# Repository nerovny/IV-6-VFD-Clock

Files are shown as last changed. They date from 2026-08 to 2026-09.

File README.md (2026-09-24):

# ИВ-6 VFD Digital Clock
+ _board: revision 1.0.0_
+ _firmware: version 0.1 Alpha_
## Overview
This is a basic 6-digit, 7-segment clock based on Soviet ИВ-6 vacuum fluorescent tubes, powered by a widely accessible STM32F103CBT6 microcontroller. 

+ No AI
+ No WiFi
+ USB-C powered

The core concept involves using a single 5V (USB-C) power source and converting the voltage to the 3.3V, 1.2V, and 30–35V levels required to operate the VFD tubes, microcontroller, and logic ICs. 
These circuits can be seen around the location of the rotary encoder on the right side of the board.

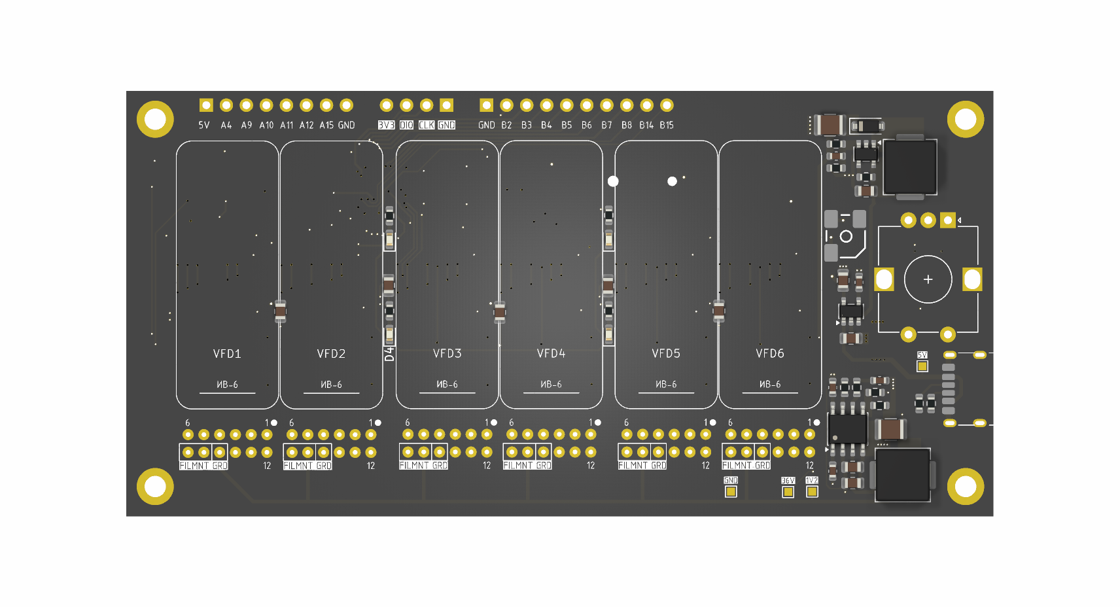
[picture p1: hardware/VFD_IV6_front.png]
main_view


The circuit employs sequential updating of CD4511 BCD-to-7-segment latches and static control of the vacuum fluorescent tubes using TBD62783A eight-channel drivers. 
The static function of the VFD eliminates the flickering, extends the life of the lamps, but requires much more ICs.

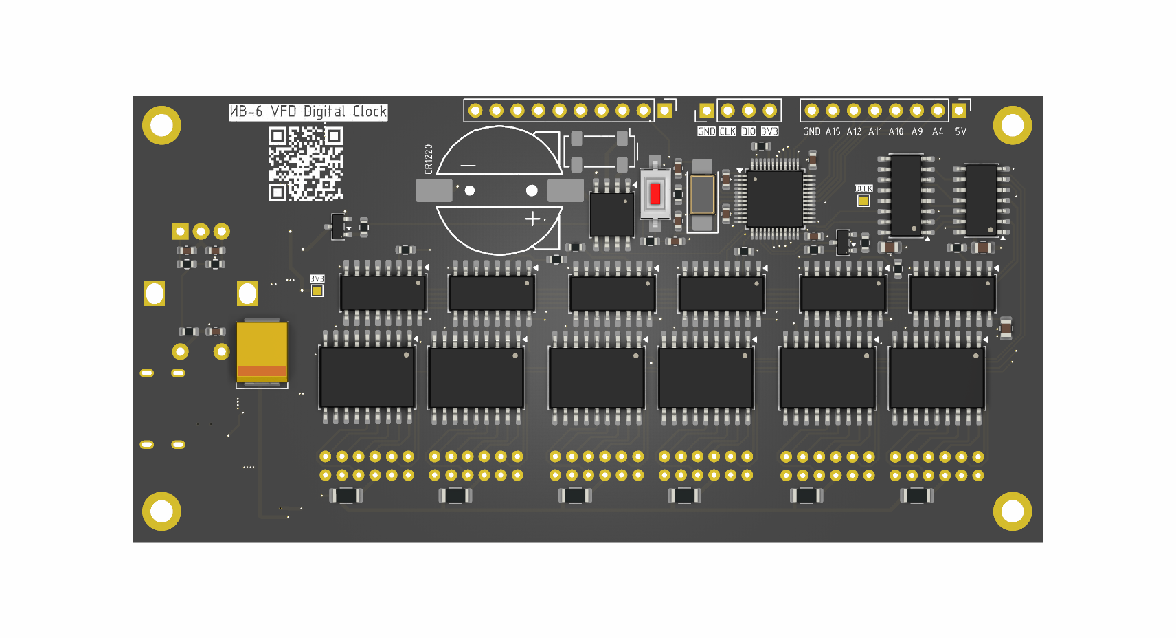
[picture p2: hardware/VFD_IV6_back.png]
rear_view


The unused MCU pins and 5v, 3v3 power rails are accessible via the 2.54mm headers and can be used for an additional LEDs, buttons, logic circuitry etc.

## Hardware
The 110x54mm 4-layer board is tight, but definitely doable by hand with the good iron. The road is mastered by the one who walks it.
+ [Interactive BOM HTML](http://htmlpreview.github.io/?https://github.com/nerovny/IV-6-VFD-Clock/blob/main/hardware/bom/ibom.html)
+ [Board dimensions](hardware/VFD_IV6_dimensions.png)
+ [Fabrication files]

## Firmware
The latest binary is [HERE](https://github.com/nerovny/IV-6-VFD-Clock/releases)

Use the onboard SWD header and STM32CubeProgrammer to flash it.

The firmware made with VSCode + PlatformIO using some HAL drivers. Source code is provided: just clone the repo and open the project with PIO VSCode plugin.

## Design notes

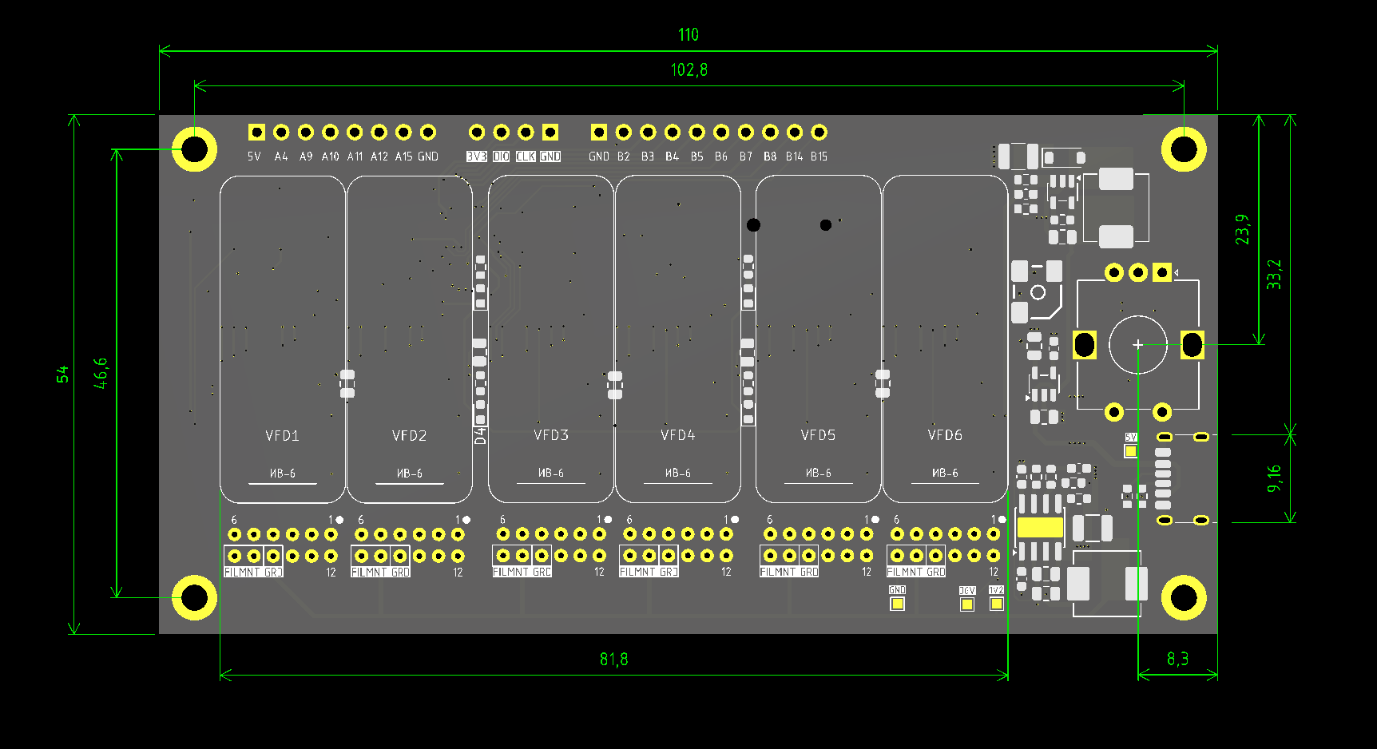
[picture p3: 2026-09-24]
hardware/VFD_IV6_dimensions.png

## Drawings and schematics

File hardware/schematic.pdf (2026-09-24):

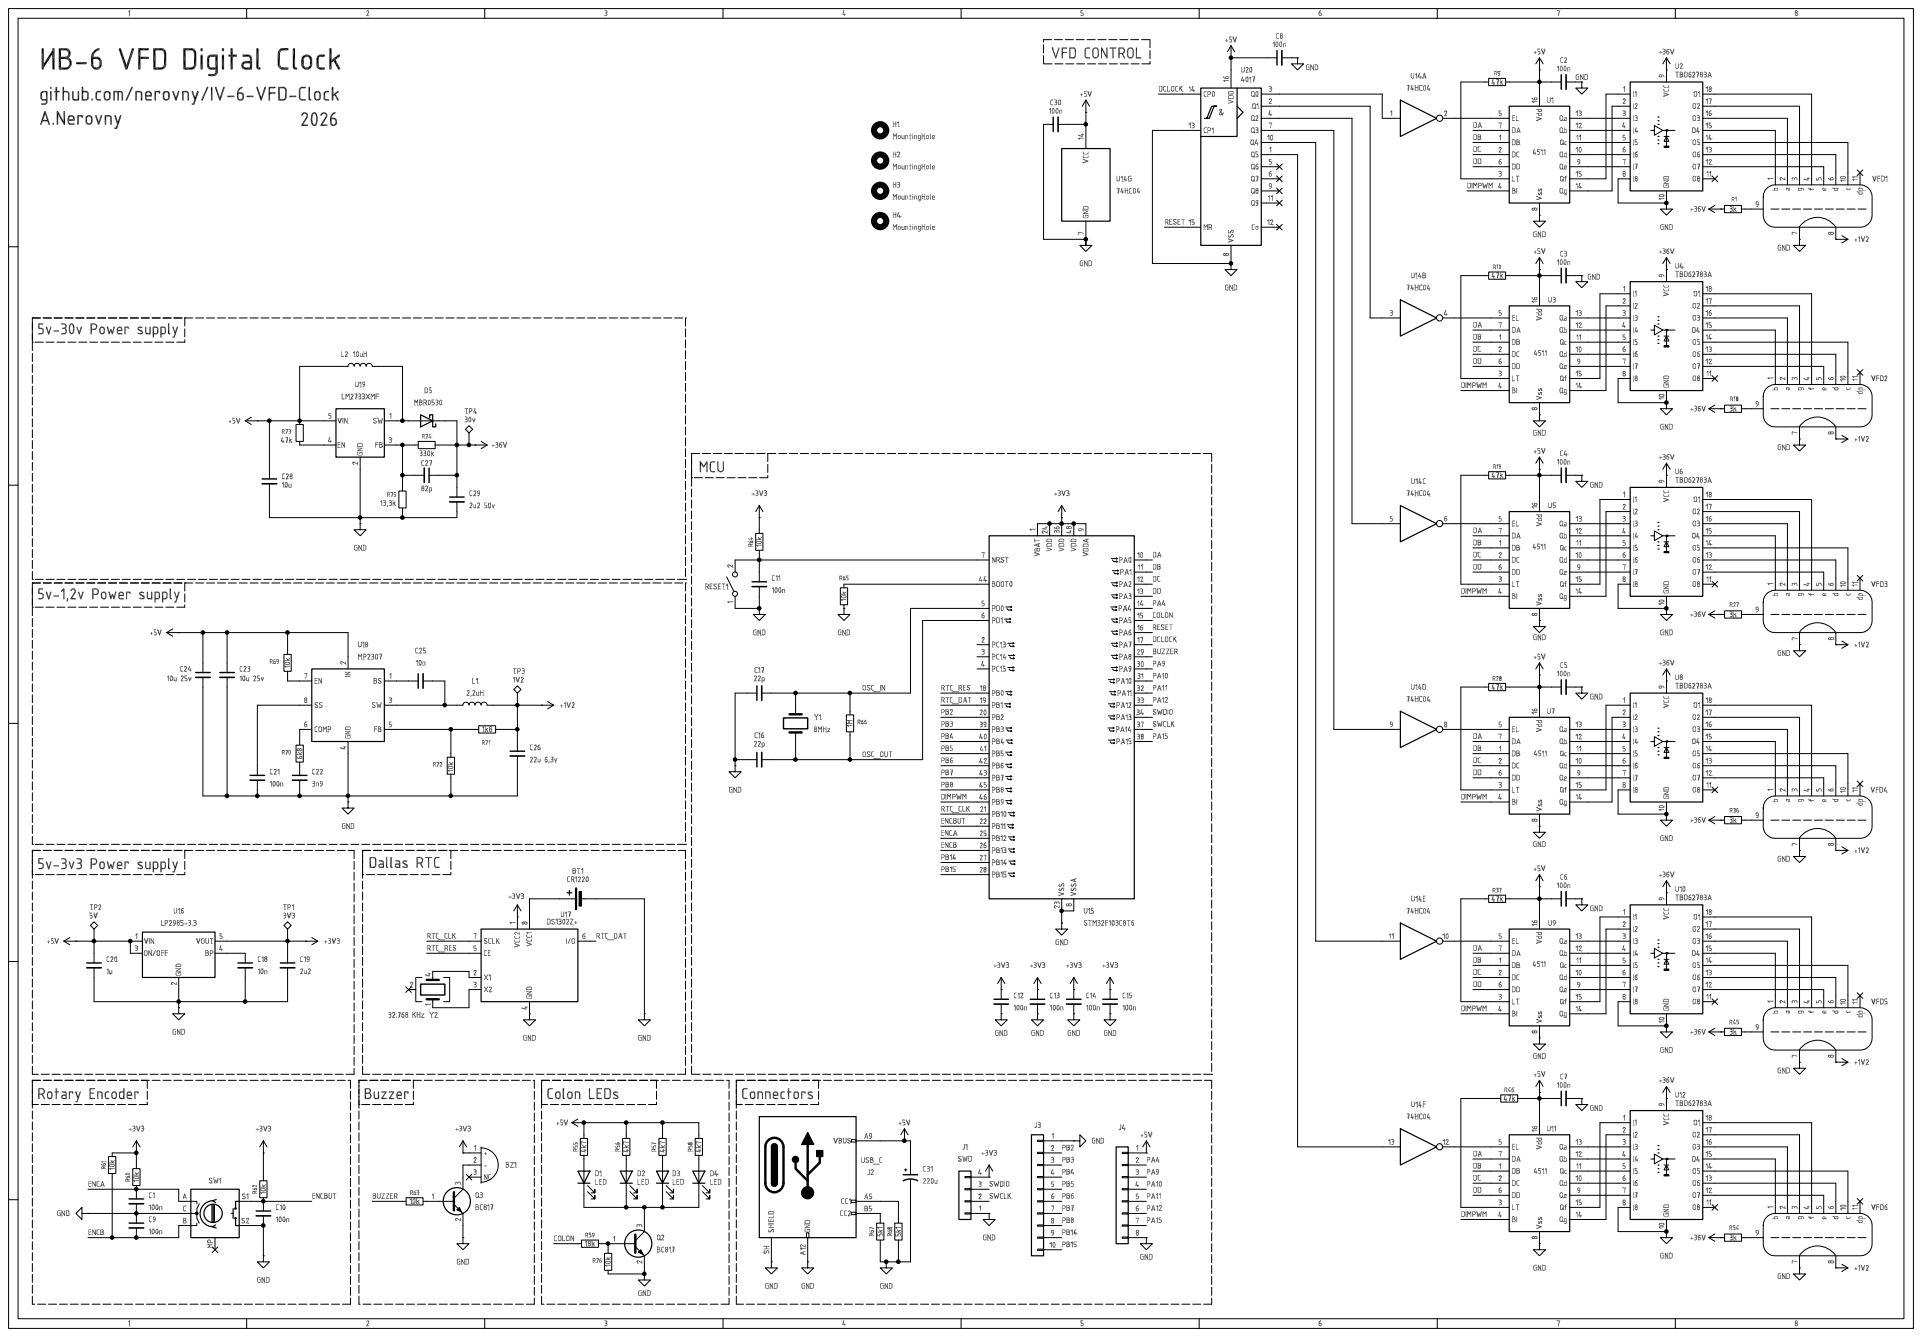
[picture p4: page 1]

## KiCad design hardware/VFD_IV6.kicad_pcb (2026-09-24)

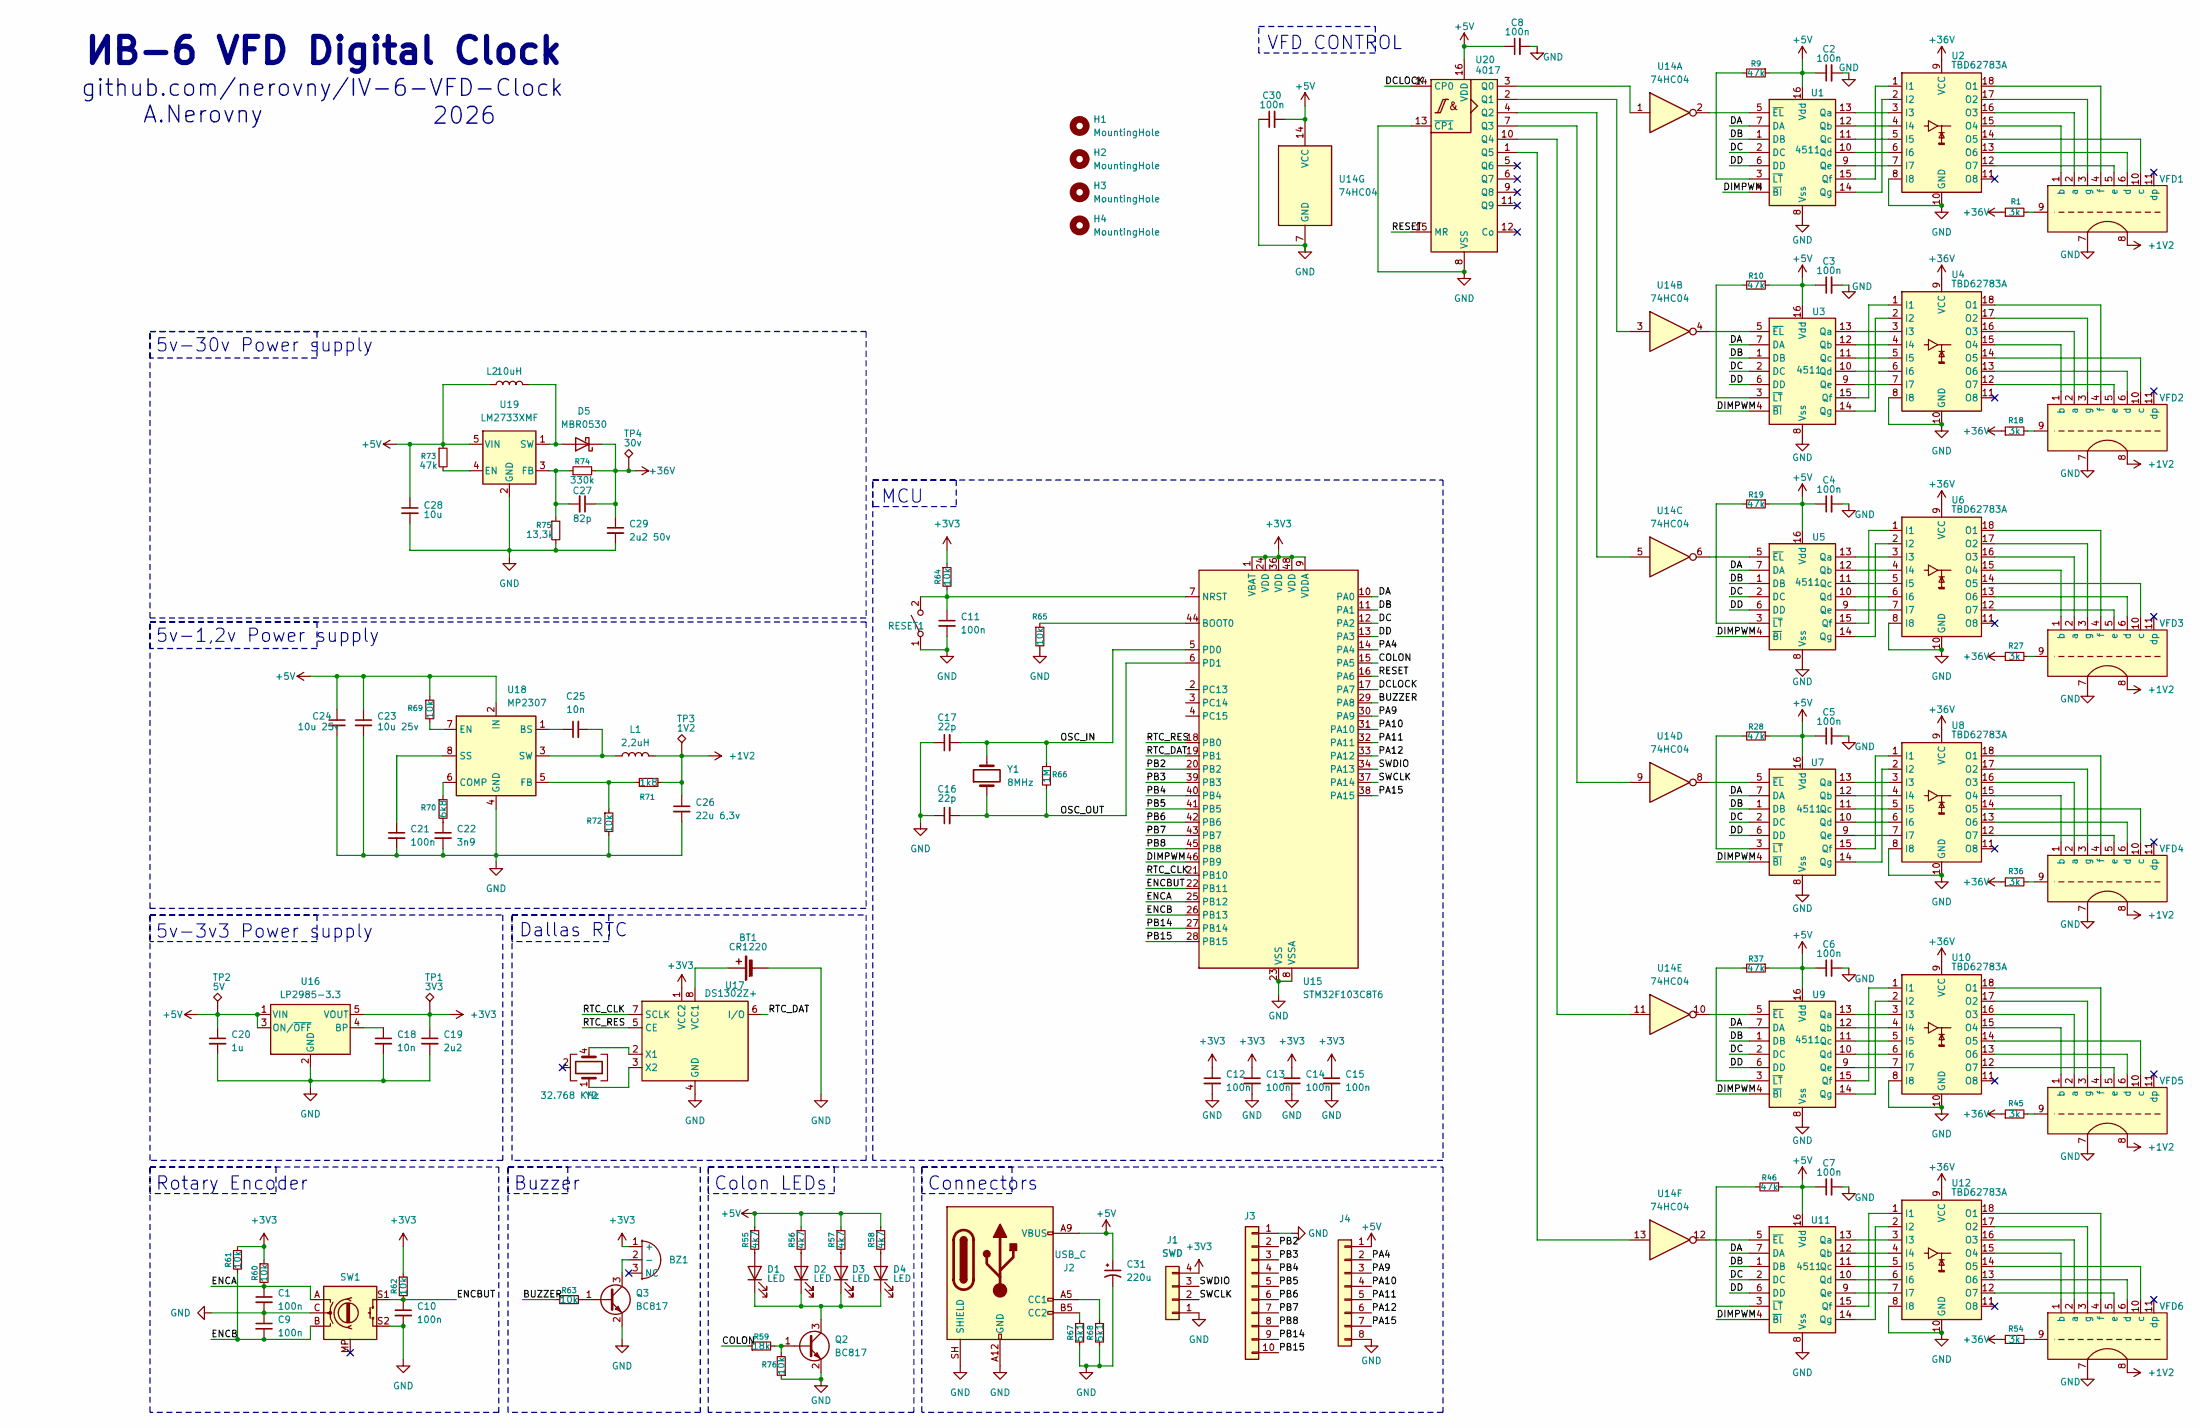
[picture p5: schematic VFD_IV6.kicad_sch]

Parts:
BT1: CR1220; RSPRO1220
BZ1: HCT5020
C1, C9, C10, C11, C12, C13, C14, C15, C21: 100n; C_0603_1608Metric
C2, C3, C4, C5, C6, C7, C8, C30: 100n; C_0805_2012Metric
C16, C17: 22p; C_0603_1608Metric
C18, C25: 10n; C_0603_1608Metric
C19: 2u2; C_0805_2012Metric
C20: 1u; C_0805_2012Metric
C22: 3n9; C_0603_1608Metric
C23, C24: 10u 25v; C_0805_2012Metric
C26: 22u 6,3v; C_1210_3225Metric
C27: 82p; C_0603_1608Metric
C28: 10u; C_0805_2012Metric
C29: 2u2 50v; C_1210_3225Metric
C31: 220u; CP_EIA-7360-38_Kemet-E
D1, D2, D3, D4: LED; LED_0603_1608Metric
D5: MBR0530; D_SOD-123
H1, H2, H3, H4: MountingHole; MountingHole_2.7mm_M2.5_DIN965_Pad
J1: SWD; PinHeader_1x04_P2.54mm_Vertical
J2: USB_C; USB_C_Receptacle_HRO_TYPE-C-31-M-17
J3: Conn_01x10; PinHeader_1x10_P2.54mm_Vertical
J4: Conn_01x06; PinHeader_1x08_P2.54mm_Vertical
L1: 2,2uH; L_APV_APH0650
L2: 10uH; L_APV_APH0650
Q2, Q3: BC817; SOT-23
R1, R18, R27, R36, R45, R54: 3k; R_1206_3216Metric
R9, R10, R19, R28, R37, R46, R73: 47k; R_0603_1608Metric
R55, R56, R57, R58: 4k7; R_0603_1608Metric
R59: 18k; R_0603_1608Metric
R60, R61, R62, R63, R64, R65, R69, R72, R76: 10k; R_0603_1608Metric
R66: 1M; R_0603_1608Metric
R67, R68: 5k1; R_0603_1608Metric
R70: 6k8; R_0603_1608Metric
R71: 1k8; R_0603_1608Metric
R74: 330k; R_0603_1608Metric
R75: 13,3k; R_0603_1608Metric
RESET1: SW_SPST; SW_SPST_CK_RS282G05A3
SW1: RotaryEncoder_Switch_MP; RotaryEncoder_Alps_EC12E-Switch_Vertical_H20mm
TP1: 3V3; TestPoint_Pad_1.0x1.0mm
TP2: 5V; TestPoint_Pad_1.0x1.0mm
TP3: 1V2; TestPoint_Pad_1.0x1.0mm
TP4: 30v; TestPoint_Pad_1.0x1.0mm
U1, U3, U5, U7, U9, U11: 4511; SOP-16_4.4x10.4mm_P1.27mm
U2, U4, U6, U8, U10, U12: TBD62783A; SOIC-18W_7.5x11.6mm_P1.27mm
U14: 74HC04; SOIC-14_3.9x8.7mm_P1.27mm
U15: STM32F103C8T6; LQFP-48_7x7mm_P0.5mm
U16: LP2985-3.3; SOT-23-5
U17: DS1302Z+; SOIC-8_5.3x5.3mm_P1.27mm
U18: MP2307; SOIC-8_3.9x4.9mm_P1.27mm
U19: LM2733XMF; SOT-23-5
U20: 4017; SOIC-16_3.9x9.9mm_P1.27mm
VFD1, VFD2, VFD3, VFD4, VFD5, VFD6: IV-6_Horizontal
Y1: 8MHz; Crystal_SMD_5032-2Pin_5.0x3.2mm_HandSoldering
Y2: 32.768 KHz; Crystal_SMD_SeikoEpson_MC306-4Pin_8.0x3.2mm

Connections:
+1V2: C26.1, L1.2, R71.2, TP3.1 (1_1), VFD1.8, VFD2.8, VFD3.8, VFD4.8, VFD5.8, VFD6.8
+3V3: BZ1.1 (+), C12.1, C13.1, C14.1, C15.1, C19.1, J1.4, R60.1, R61.1, R62.1, R64.1, TP1.1 (1_1), U15.1 (VBAT), U15.9 (VDDA), U15.24 (VDD), U15.36 (VDD), U15.48 (VDD), U16.5 (VOUT), U17.1 (VCC2)
+5V: C2.1, C3.1, C4.1, C5.1, C6.1, C7.1, C8.1, C20.1, C23.1, C24.1, C28.1, C30.2, C31.1, J2.A9 (VBUS), J2.B9 (VBUS), J4.1, L2.1, R9.1, R10.1, R19.1, R28.1, R37.1, R46.1, R55.1, R56.1, R57.1, R58.1, R69.1, R73.1, TP2.1 (1_1), U1.16 (Vdd), U3.16 (Vdd), U5.16 (Vdd), U7.16 (Vdd), U9.16 (Vdd), U11.16 (Vdd), U14.14 (VCC), U16.1 (VIN), U16.3 (ON/~OFF), U18.2 (IN), U19.5 (VIN), U20.16 (VDD)
/BUZZER: R63.1, U15.29 (PA8)
/COLON: R59.1, U15.15 (PA5)
/DA: U1.7 (DA), U3.7 (DA), U5.7 (DA), U7.7 (DA), U9.7 (DA), U11.7 (DA), U15.10 (PA0)
/DB: U1.1 (DB), U3.1 (DB), U5.1 (DB), U7.1 (DB), U9.1 (DB), U11.1 (DB), U15.11 (PA1)
/DC: U1.2 (DC), U3.2 (DC), U5.2 (DC), U7.2 (DC), U9.2 (DC), U11.2 (DC), U15.12 (PA2)
/DCLOCK: U15.17 (PA7), U20.14 (CP0); also elsewhere on the board
/DD: U1.6 (DD), U3.6 (DD), U5.6 (DD), U7.6 (DD), U9.6 (DD), U11.6 (DD), U15.13 (PA3)
/DIMPWM: U1.4 (~BI), U3.4 (~BI), U5.4 (~BI), U7.4 (~BI), U9.4 (~BI), U11.4 (~BI), U15.46 (PB9)
/ENCA: C1.1, R60.2, SW1.A, U15.25 (PB12)
/ENCB: C9.2, R61.2, SW1.B, U15.26 (PB13)
/ENCBUT: C10.1, R62.2, SW1.S1, U15.22 (PB11)
/OSC_IN: C17.2, R66.1, U15.5 (PD0), Y1.2
/OSC_OUT: C16.2, R66.2, U15.6 (PD1), Y1.1
/PA4: J4.2, U15.14 (PA4)
/PA9: J4.3, U15.30 (PA9)
/PA10: J4.4, U15.31 (PA10)
/PA11: J4.5, U15.32 (PA11)
/PA12: J4.6, U15.33 (PA12)
/PA15: J4.7, U15.38 (PA15)
/PB2: J3.2, U15.20 (PB2)
/PB3: J3.3, U15.39 (PB3)
/PB4: J3.4, U15.40 (PB4)
/PB5: J3.5, U15.41 (PB5)
/PB6: J3.6, U15.42 (PB6)
/PB7: J3.7, U15.43 (PB7)
/PB8: J3.8, U15.45 (PB8)
/PB14: J3.9, U15.27 (PB14)
/PB15: J3.10, U15.28 (PB15)
/RESET: U15.16 (PA6), U20.15 (MR)
/RTC_CLK: U15.21 (PB10), U17.7 (SCLK)
/RTC_DAT: U15.19 (PB1), U17.6 (I/O)
/RTC_RES: U15.18 (PB0), U17.5 (CE)
/SWCLK: J1.2, U15.37 (PA14)
/SWDIO: J1.3, U15.34 (PA13)
unnamed: BT1.1 (+), U17.8 (VCC1)
unnamed: BZ1.2 (-), Q3.3 (C)
unnamed: C22.1, R70.2
unnamed: D1.2 (A), R55.2
unnamed: D1.1 (K), D2.1 (K), D3.1 (K), D4.1 (K), Q2.3 (C)
unnamed: D2.2 (A), R56.2
unnamed: D3.2 (A), R57.2
unnamed: D4.2 (A), R58.2
unnamed: D5.2 (A), L2.2, U19.1 (SW)
unnamed: J2.A5 (CC1), R68.1
unnamed: J2.B5 (CC2), R67.1
unnamed: Q2.1 (B), R59.2, R76.2
unnamed: Q3.1 (B), R63.2
unnamed: R1.2, VFD1.9
unnamed: R18.2, VFD2.9
unnamed: R27.2, VFD3.9
unnamed: R36.2, VFD4.9
unnamed: R45.2, VFD5.9
unnamed: R54.2, VFD6.9
unnamed: C11.1, R64.2, RESET1.2 (B), U15.7 (NRST)
unnamed: U1.13 (Qa), U2.3 (I3)
unnamed: U1.12 (Qb), U2.4 (I4)
unnamed: U1.11 (Qc), U2.5 (I5)
unnamed: U1.10 (Qd), U2.6 (I6)
unnamed: U1.9 (Qe), U2.7 (I7)
unnamed: U1.15 (Qf), U2.1 (I1)
unnamed: U1.14 (Qg), U2.2 (I2)
unnamed: U1.5 (~EL), U14.2
unnamed: R9.2, U1.3 (~LT)
unnamed: U2.18 (O1), VFD1.4 (f)
unnamed: U2.17 (O2), VFD1.3 (g)
unnamed: U2.16 (O3), VFD1.2 (a)
unnamed: U2.15 (O4), VFD1.1 (b)
unnamed: U2.14 (O5), VFD1.10 (c)
unnamed: U2.13 (O6), VFD1.6 (d)
unnamed: U2.12 (O7), VFD1.5 (e)
unnamed: U3.13 (Qa), U4.3 (I3)
unnamed: U3.12 (Qb), U4.4 (I4)
unnamed: U3.11 (Qc), U4.5 (I5)
unnamed: U3.10 (Qd), U4.6 (I6)
unnamed: U3.9 (Qe), U4.7 (I7)
unnamed: U3.15 (Qf), U4.1 (I1)
unnamed: U3.14 (Qg), U4.2 (I2)
unnamed: U3.5 (~EL), U14.4
unnamed: R10.2, U3.3 (~LT)
unnamed: U4.18 (O1), VFD2.4 (f)
unnamed: U4.17 (O2), VFD2.3 (g)
unnamed: U4.16 (O3), VFD2.2 (a)
unnamed: U4.15 (O4), VFD2.1 (b)
unnamed: U4.14 (O5), VFD2.10 (c)
unnamed: U4.13 (O6), VFD2.6 (d)
unnamed: U4.12 (O7), VFD2.5 (e)
unnamed: U5.13 (Qa), U6.3 (I3)
unnamed: U5.12 (Qb), U6.4 (I4)
unnamed: U5.11 (Qc), U6.5 (I5)
unnamed: U5.10 (Qd), U6.6 (I6)
unnamed: U5.9 (Qe), U6.7 (I7)
unnamed: U5.15 (Qf), U6.1 (I1)
unnamed: U5.14 (Qg), U6.2 (I2)
unnamed: U5.5 (~EL), U14.6
unnamed: R19.2, U5.3 (~LT)
unnamed: U6.18 (O1), VFD3.4 (f)
unnamed: U6.17 (O2), VFD3.3 (g)
unnamed: U6.16 (O3), VFD3.2 (a)
unnamed: U6.15 (O4), VFD3.1 (b)
unnamed: U6.14 (O5), VFD3.10 (c)
unnamed: U6.13 (O6), VFD3.6 (d)
unnamed: U6.12 (O7), VFD3.5 (e)
unnamed: U7.13 (Qa), U8.3 (I3)
unnamed: U7.12 (Qb), U8.4 (I4)
unnamed: U7.11 (Qc), U8.5 (I5)
unnamed: U7.10 (Qd), U8.6 (I6)
unnamed: U7.9 (Qe), U8.7 (I7)
unnamed: U7.15 (Qf), U8.1 (I1)
unnamed: U7.14 (Qg), U8.2 (I2)
unnamed: U7.5 (~EL), U14.8
unnamed: R28.2, U7.3 (~LT)
unnamed: U8.18 (O1), VFD4.4 (f)
unnamed: U8.17 (O2), VFD4.3 (g)
unnamed: U8.16 (O3), VFD4.2 (a)
unnamed: U8.15 (O4), VFD4.1 (b)
unnamed: U8.14 (O5), VFD4.10 (c)
unnamed: U8.13 (O6), VFD4.6 (d)
unnamed: U8.12 (O7), VFD4.5 (e)
unnamed: U9.5 (~EL), U14.10
unnamed: R37.2, U9.3 (~LT)
unnamed: U9.15 (Qf), U10.1 (I1)
unnamed: U9.14 (Qg), U10.2 (I2)
unnamed: U9.13 (Qa), U10.3 (I3)
unnamed: U9.12 (Qb), U10.4 (I4)
unnamed: U9.11 (Qc), U10.5 (I5)
unnamed: U9.10 (Qd), U10.6 (I6)
unnamed: U9.9 (Qe), U10.7 (I7)
unnamed: U10.18 (O1), VFD5.4 (f)
unnamed: U10.17 (O2), VFD5.3 (g)
unnamed: U10.16 (O3), VFD5.2 (a)
unnamed: U10.15 (O4), VFD5.1 (b)
unnamed: U10.14 (O5), VFD5.10 (c)
unnamed: U10.13 (O6), VFD5.6 (d)
unnamed: U10.12 (O7), VFD5.5 (e)
unnamed: U11.13 (Qa), U12.3 (I3)
unnamed: U11.12 (Qb), U12.4 (I4)
unnamed: U11.11 (Qc), U12.5 (I5)
unnamed: U11.10 (Qd), U12.6 (I6)
unnamed: U11.9 (Qe), U12.7 (I7)
unnamed: U11.15 (Qf), U12.1 (I1)
unnamed: U11.14 (Qg), U12.2 (I2)
unnamed: U11.5 (~EL), U14.12
unnamed: R46.2, U11.3 (~LT)
unnamed: U12.18 (O1), VFD6.4 (f)
unnamed: U12.17 (O2), VFD6.3 (g)
unnamed: U12.16 (O3), VFD6.2 (a)
unnamed: U12.15 (O4), VFD6.1 (b)
unnamed: U12.14 (O5), VFD6.10 (c)
unnamed: U12.13 (O6), VFD6.6 (d)
unnamed: U12.12 (O7), VFD6.5 (e)
unnamed: R65.1, U15.44 (BOOT0)
unnamed: C18.1, U16.4 (BP)
unnamed: U17.2 (X1), Y2.4
unnamed: U17.3 (X2), Y2.1
unnamed: C25.1, U18.1 (BS)
unnamed: R70.1, U18.6 (COMP)
unnamed: R69.2, U18.7 (EN)
unnamed: R71.1, R72.1, U18.5 (FB)
unnamed: C21.1, U18.8 (SS)
unnamed: C25.2, L1.1, U18.3 (SW)
unnamed: R73.2, U19.4 (EN)
unnamed: C27.2, R74.1, R75.1, U19.3 (FB)
unnamed: U14.1, U20.3 (Q0)
unnamed: U14.3, U20.2 (Q1)
unnamed: U14.5, U20.4 (Q2)
unnamed: U14.9, U20.7 (Q3)
unnamed: U14.11, U20.10 (Q4)
unnamed: U14.13, U20.1 (Q5)

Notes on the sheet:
5v-3v3 Power supply
5v-1,2v Power supply
VFD CONTROL
MCU
github.com/nerovny/IV-6-VFD-Clock
ИВ-6 VFD Digital Clock
Dallas RTC
Colon LEDs
Buzzer
A.Nerovny
2026
Connectors
5v-30v Power supply
Rotary Encoder

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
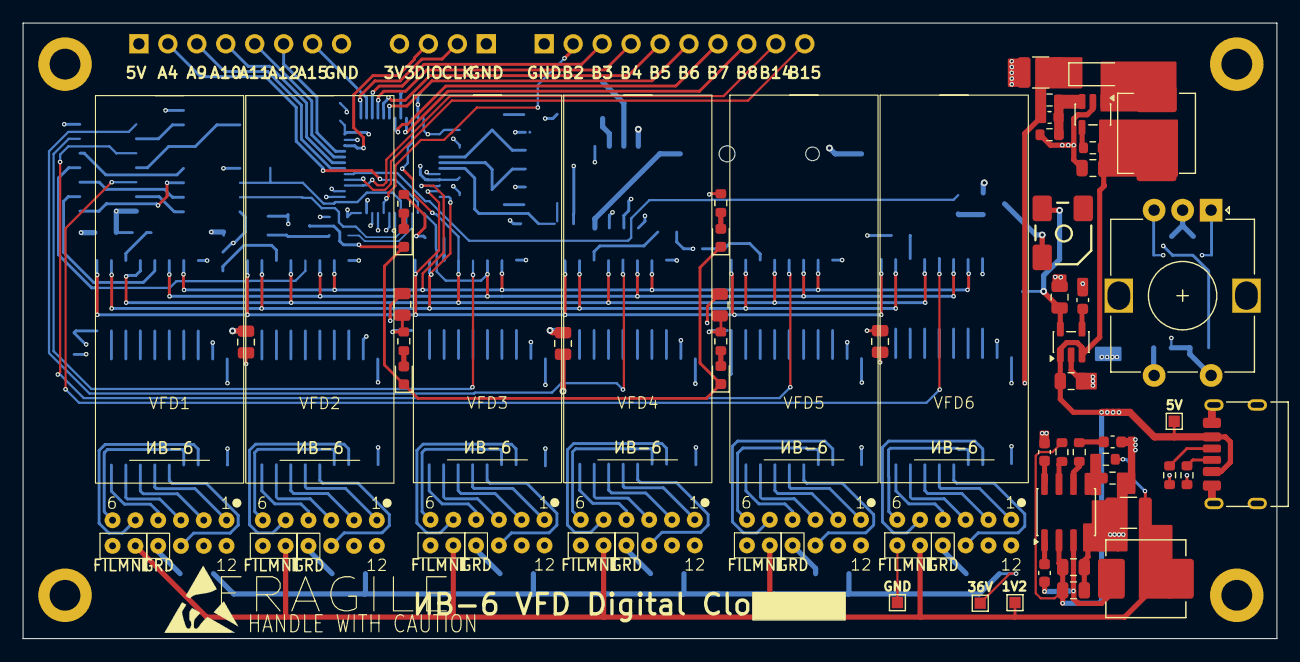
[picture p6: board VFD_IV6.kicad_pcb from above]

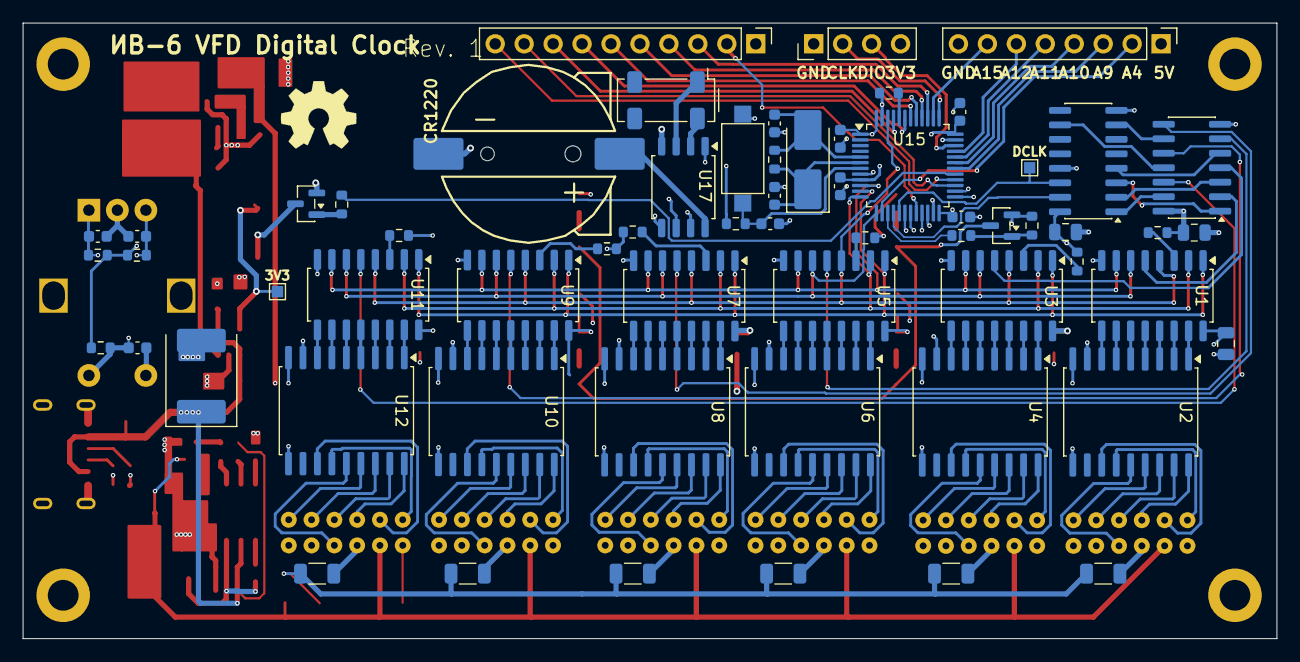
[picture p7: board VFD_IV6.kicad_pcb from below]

Board: 4 copper layers, 110.0 x 54.0 mm, 119 parts (62 on the bottom side), 173 nets.

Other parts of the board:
TP4#2, TP4#3: 30v; TestPoint_Pad_1.0x1.0mm

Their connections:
/DCLOCK: TP4#3.1 (1_1); also elsewhere on the board

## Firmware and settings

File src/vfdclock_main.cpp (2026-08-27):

/********************************************************************************
  * @file     VFD Clock
  * @author   A. Nerovny
  * @brief    Under construction
  *******************************************************************************/
// TODO: 	LM2733YMFX/NOPB - 40В
// 			LMR64010XMF - 40v

#include "stm32f1xx_hal.h"
#include "stm32f1xx_hal_gpio.h"
#include "stm32f1xx_hal_rcc.h"
#include "stm32f1xx_hal_rtc.h"
#include "stm32f1xx_hal_rtc_ex.h"
#include "stm32f1xx_hal_tim.h"
#include "clock_pins.h"
#include "clock_bcd.h" 
#include "ds1302.h"
#include "delay.h"
#include "buzzer.h"
#include "encoder.h"

const char* DaysName[] = {0, "MON", "TUE", "WED", "THU", "FRI", "SAT", "SUN"};

typedef enum {
	CLOCK_STATE_NORMAL, //Default
	CLOCK_STATE_ENCODER_TEST,
	CLOCK_STATE_SET_HOUR,
	CLOCK_STATE_SET_MINUTE,
	CLOCK_STATE_SET_SECOND 
} Clock_State_t;

typedef enum {
	BUTTON_IDLE,
	BUTTON_PRESSED
} Button_State_t;

Clock_State_t STATE = CLOCK_STATE_NORMAL;
Button_State_t BUTTON_STATE = BUTTON_IDLE;

uint8_t ClockTestCounter = 0;
uint8_t ClockSetHour = 0;
uint8_t ClockSetMinute = 0;
uint8_t ClockSetSecond = 0;

Encoder_t Encoder = {
	RE_Count : 0,
	Rotation : Encoder_Rotate_Nothing, 
	Mode : Encoder_Mode_Normal,
	GPIO_A : ENCODER_PORT,
	GPIO_B : ENCODER_PORT,
	GPIO_BTN : ENCODER_PORT,
	GPIO_PIN_A : ENCODER_PIN_ENA,
	GPIO_PIN_B : ENCODER_PIN_ENB,
	GPIO_PIN_BTN : ENCODER_PIN_BTN
	};

void SystemClock_Config(void);
void _Error_Handler(const char* file, int line);

int main(void) {
	HAL_Init();
	SystemClock_Config();
	DigitPins_Init();
	BuzzerInit();
	HAL_Delay(10);

	DS1302_HandelTypeDef rtc = {
        .CE_Pin = {RTC_PORT, RTC_PIN_RESET},
        .IO_Pin = {RTC_PORT, RTC_PIN_DATA},
		.SCLK_Pin = {RTC_PORT, RTC_PIN_CLK}
    };

	// ONLY FOR TESTING PURPOSES // Set the initial date and time
    DS1302_TimeRecord datetime = {
        .sec = 0,
        .min = 2,
        .hour = {.hour=14, .meridiem=NONE}, // Set meridiem to NONE if using 24 hrs clock
        .date = 22,
        .month = 8,
        .year = 24,
        .day = TUE
    };

	Encoder_Init(&Encoder);

	RTCPins_Init();
	ds1302_init(&rtc);
	//ds1302_setDateTime(&rtc, datetime);
	BuzzerStartDuration(1100, 50, 100);
	DigitBCDStartupRoll();
	DigitBCDReset();
	BuzzerStartDuration(1700, 50, 200);

	//force the initial button state
	BUTTON_STATE = BUTTON_IDLE;

	while (1) { // MAIN LOOP
		BuzzerUpdate();

		switch (STATE) {
			case CLOCK_STATE_NORMAL: {
				DS1302_TimeRecord now = ds1302_getDateTime(&rtc);
				if (now.sec != datetime.sec) {
					datetime = ds1302_getDateTime(&rtc);
					DigitBCDPrint(datetime.hour.hour, datetime.min, datetime.sec);
					HAL_GPIO_TogglePin(DIGIT_BCD_PORT, DIGIT_BCD_PIN_COLON);
				}
				if (BUTTON_STATE == BUTTON_PRESSED) {
					BUTTON_STATE = BUTTON_IDLE;
					STATE = CLOCK_STATE_SET_HOUR;
					datetime = ds1302_getDateTime(&rtc);
					ClockSetHour = datetime.hour.hour;
					ClockSetMinute = datetime.min;
					ClockSetSecond = datetime.sec;
					break;
				}
				break;
			}
			case CLOCK_STATE_ENCODER_TEST: {
				Encoder_Rotation_t Rotation;
				Rotation = Encoder_Get(&Encoder);
				if (Rotation == Encoder_Rotate_Increment) {
					if (ClockTestCounter < 99) {
						ClockTestCounter += 1;
					}
				} else if (Rotation == Encoder_Rotate_Decrement) {
					if (ClockTestCounter > 0) {
						ClockTestCounter -= 1;
					} else (ClockTestCounter = 0);
				}
				DigitBCDPrint(100, 100, ClockTestCounter);
				break;
			}
			case CLOCK_STATE_SET_HOUR: {
				Encoder_Rotation_t Rotation;
				Rotation = Encoder_Get(&Encoder);
				if (Rotation == Encoder_Rotate_Increment) {
					if (ClockSetHour < 23) {
						ClockSetHour += 1;
					}
				} else if (Rotation == Encoder_Rotate_Decrement) {
					if (ClockSetHour > 0) {
						ClockSetHour -= 1;
					} else (ClockSetHour = 0);
				}
				DigitBCDPrint(ClockSetHour, 100, 100);

				if (BUTTON_STATE == BUTTON_PRESSED) {
					BUTTON_STATE = BUTTON_IDLE;
					STATE = CLOCK_STATE_SET_MINUTE;
					break;
				}
				break;
			}
			case CLOCK_STATE_SET_MINUTE: {
				Encoder_Rotation_t Rotation;
				Rotation = Encoder_Get(&Encoder);
				if (Rotation == Encoder_Rotate_Increment) {
					if (ClockSetMinute < 59) {
						ClockSetMinute += 1;
					}
				} else if (Rotation == Encoder_Rotate_Decrement) {
					if (ClockSetMinute > 0) {
						ClockSetMinute -= 1;
					} else (ClockSetMinute = 0);
				}
				DigitBCDPrint(ClockSetHour, ClockSetMinute, 100);

				if (BUTTON_STATE == BUTTON_PRESSED) {
					BUTTON_STATE = BUTTON_IDLE;
					STATE = CLOCK_STATE_SET_SECOND;
					break;
				}
				break;
			}
			case CLOCK_STATE_SET_SECOND: {
				Encoder_Rotation_t Rotation;
				Rotation = Encoder_Get(&Encoder);
				if (Rotation == Encoder_Rotate_Increment) {
					if (ClockSetSecond < 59) {
						ClockSetSecond += 1;
					}
				} else if (Rotation == Encoder_Rotate_Decrement) {
					if (ClockSetSecond > 0) {
						ClockSetSecond -= 1;
					} else (ClockSetSecond = 0);
				}
				DigitBCDPrint(ClockSetHour, ClockSetMinute, ClockSetSecond);

				if (BUTTON_STATE == BUTTON_PRESSED) {
					BUTTON_STATE = BUTTON_IDLE;
					STATE = CLOCK_STATE_NORMAL;
					datetime = {
        				.sec = ClockSetSecond,
        				.min = ClockSetMinute,
        				.hour = {.hour=ClockSetHour, .meridiem=NONE}, // Set meridiem to NONE if using 24 hrs clock
        				.date = 22,
        				.month = 8,
        				.year = 24,
        				.day = TUE
    				};
					ds1302_setDateTime(&rtc, datetime);
					break;
				}
				break;
			}
			default:
				break;
		}
	} // MAIN LOOP END
	return 0;
}

void SystemClock_Config(void) {

	__HAL_RCC_PWR_CLK_ENABLE();

	RCC_OscInitTypeDef RCC_OscInitStruct;
	RCC_ClkInitTypeDef RCC_ClkInitStruct;
	RCC_OscInitStruct.OscillatorType = RCC_OSCILLATORTYPE_HSE | RCC_OSCILLATORTYPE_LSE;
	RCC_OscInitStruct.HSEState = RCC_HSE_ON;
	RCC_OscInitStruct.HSEPredivValue = RCC_HSE_PREDIV_DIV1;
	RCC_OscInitStruct.LSIState = RCC_LSE_ON;
	RCC_OscInitStruct.PLL.PLLState = RCC_PLL_ON;
	RCC_OscInitStruct.PLL.PLLSource = RCC_PLLSOURCE_HSE;
	RCC_OscInitStruct.PLL.PLLMUL = RCC_PLL_MUL9;

	if (HAL_RCC_OscConfig(&RCC_OscInitStruct) != HAL_OK) {
		_Error_Handler(__FILE__, __LINE__);
  	}

	RCC_ClkInitStruct.ClockType = RCC_CLOCKTYPE_HCLK|RCC_CLOCKTYPE_SYSCLK
				|RCC_CLOCKTYPE_PCLK1|RCC_CLOCKTYPE_PCLK2;
	RCC_ClkInitStruct.SYSCLKSource = RCC_SYSCLKSOURCE_PLLCLK;
	RCC_ClkInitStruct.AHBCLKDivider = RCC_SYSCLK_DIV1;
	RCC_ClkInitStruct.APB1CLKDivider = RCC_HCLK_DIV2;
	RCC_ClkInitStruct.APB2CLKDivider = RCC_HCLK_DIV1;

	if (HAL_RCC_ClockConfig(&RCC_ClkInitStruct, 
				FLASH_LATENCY_2) != HAL_OK) {
		_Error_Handler(__FILE__, __LINE__);
	}

	//Configure the SysTick frequency, clock source and interrupt priority.
	// HAL_Delay(1) is 1ms
	HAL_SYSTICK_Config(HAL_RCC_GetHCLKFreq()/1000);
	HAL_SYSTICK_CLKSourceConfig(SYSTICK_CLKSOURCE_HCLK);
	HAL_NVIC_SetPriority(SysTick_IRQn, 0, 0);
}

void _Error_Handler(const char* file, int line) {
	//Error occured so we did nothing
}

extern "C" void EXTI15_10_IRQHandler(void) {
  	HAL_GPIO_EXTI_IRQHandler(ENCODER_PIN_ENA);
	HAL_GPIO_EXTI_IRQHandler(ENCODER_PIN_BTN);
}

void HAL_GPIO_EXTI_Callback(uint16_t GPIO_Pin) {
	__HAL_GPIO_EXTI_CLEAR_IT(ENCODER_PIN_ENA);
	__HAL_GPIO_EXTI_CLEAR_IT(ENCODER_PIN_BTN);
  	if (GPIO_Pin == ENCODER_PIN_ENA) {
    	Encoder_Process(&Encoder);
  	}
	if (GPIO_Pin == ENCODER_PIN_BTN) {
		BUTTON_STATE = BUTTON_PRESSED;
	}
}

extern "C" void SysTick_Handler(void) {
	HAL_IncTick();
	HAL_SYSTICK_IRQHandler();
}

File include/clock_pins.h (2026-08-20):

/*
*   @file   clock_pins.h
*   @brief  Pins definitions and inits header file
*/

#include "stm32f1xx_hal.h"
#include "stm32f1xx_hal_gpio.h"

// VFD board pins
//
#define DIGIT_BCD_PORT			GPIOA
#define	DIGIT_BCD_PIN_A			GPIO_PIN_0 //A0
#define	DIGIT_BCD_PIN_B			GPIO_PIN_1 //A1
#define	DIGIT_BCD_PIN_C			GPIO_PIN_2 //A2
#define	DIGIT_BCD_PIN_D			GPIO_PIN_3 //A3
#define	DIGIT_BCD_PIN_CLK		GPIO_PIN_4 //A4
#define	DIGIT_BCD_PIN_COLON		GPIO_PIN_5 //A5
#define DIGIT_BCD_PIN_RESET		GPIO_PIN_6 //A6
#define DIGIT_PWM_PORT			GPIOB
#define DIGIT_PWM_PIN			GPIO_PIN_9 // TIM4 CH4


// DS1302 module pins
// 
#define RTC_PORT                GPIOB
#define RTC_PIN_RESET           GPIO_PIN_0
#define RTC_PIN_DATA            GPIO_PIN_1
#define RTC_PIN_CLK             GPIO_PIN_10

// Rotary encoder pins on the TIM1
#define ENCODER_PORT            GPIOB       // TODO: GPIOA
#define ENCODER_PIN_BTN         GPIO_PIN_11 // GPIO_PIN_10
#define ENCODER_PIN_ENA         GPIO_PIN_12 // GPIO_PIN_8
#define ENCODER_PIN_ENB         GPIO_PIN_13 // GPIO_PIN_9
 
// Buzzer pin on the TIM4 CH3
#define BUZZER_PORT             GPIOA       // TODO: GPIOB
#define BUZZER_PIN              GPIO_PIN_8  // GPIO_PIN_8

void DigitPins_Init(void);
void RTCPins_Init(void);

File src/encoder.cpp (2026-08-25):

#include "encoder.h"
#include "stm32f1xx_hal_gpio.h"

void Encoder_Init(Encoder_t* data) {
    __HAL_RCC_GPIOB_CLK_ENABLE();
    __HAL_RCC_AFIO_CLK_ENABLE();
    GPIO_InitTypeDef GPIO_InitStruct = {0};
	GPIO_InitStruct.Pin = data->GPIO_PIN_A;
	GPIO_InitStruct.Mode = GPIO_MODE_IT_RISING;
	GPIO_InitStruct.Pull = GPIO_PULLUP;
	HAL_GPIO_Init(data->GPIO_A, &GPIO_InitStruct);

    GPIO_InitStruct.Pin = data->GPIO_PIN_B;
	GPIO_InitStruct.Mode = GPIO_MODE_INPUT;
	GPIO_InitStruct.Pull = GPIO_PULLUP;
    GPIO_InitStruct.Speed = GPIO_SPEED_FREQ_HIGH;
	HAL_GPIO_Init(data->GPIO_B, &GPIO_InitStruct);

    GPIO_InitStruct.Pin = data->GPIO_PIN_BTN;
	GPIO_InitStruct.Mode = GPIO_MODE_IT_RISING;
	GPIO_InitStruct.Pull = GPIO_PULLUP;
	HAL_GPIO_Init(data->GPIO_BTN, &GPIO_InitStruct);

    // Enable and set EXTI15_10 Interrupt in the NVIC
    HAL_NVIC_SetPriority(EXTI15_10_IRQn, 2, 0);
    HAL_NVIC_EnableIRQ(EXTI15_10_IRQn);

    /* Set default mode */
    //data->Mode = Encoder_Mode_Normal;

    /* Set defaults */
    data->RE_Count = 0;
}

Encoder_Rotation_t Encoder_Get(Encoder_t* data) {
    if (data->RE_Count < 0) {
        data->Rotation = Encoder_Rotate_Decrement;
        data->RE_Count = 0;
        return Encoder_Rotate_Decrement;
    } else if (data->RE_Count > 0) {
        data->Rotation = Encoder_Rotate_Increment;
        data->RE_Count = 0;
        return Encoder_Rotate_Increment;
    }

    data->Rotation = Encoder_Rotate_Nothing;
    data->RE_Count = 0;
    return Encoder_Rotate_Nothing;
}

void Encoder_SetMode(Encoder_t* data, Encoder_Mode_t mode) {
    data->Mode = mode;
}

void Encoder_Process(Encoder_t* data) {
    uint8_t now_b;
    now_b = HAL_GPIO_ReadPin(data->GPIO_B, data->GPIO_PIN_B);

    if (now_b == 1) data->RE_Count++;
    else data->RE_Count--;
}

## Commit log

2026-06-15 Fixed BCDZero and BCDReset functions
    [vfdclock.cpp]
2026-06-18 Added hardware Kicad project files
    [VFD_IV6.kicad_pcb, VFD_IV6.kicad_sch]
2026-06-19 Updated schematic pdf
    [VFD_IV6.kicad_sch]
2026-08-20 Damn encoder finally working yay
2026-08-25 Unused segments ghosting fix + minor changes
    [clock_bcd.cpp, clock_pins.cpp, encoder.cpp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]
2026-08-27 Updated schematic
    [VFD_IV6.kicad_sch]
2026-08-28 New board draft
    [VFD_IV6.kicad_pcb, VFD_IV6.kicad_sch]
2026-09-23 New 4-layer board layout
    [VFD_IV6.kicad_pcb, VFD_IV6.kicad_sch]
2026-09-24 Updated schematics pdf
    [VFD_IV6.kicad_sch]
2026-09-24 Updated board pics
2026-09-24 Updated kicad project + iBOM
    [VFD_IV6.kicad_pcb]
2026-09-24 Added Gerber+DRL fabrication files
    [VFD_IV6-B_Cu.gbl, VFD_IV6-B_Mask.gbs, VFD_IV6-B_Paste.gbp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]
2026-09-24 Updated the board
    [VFD_IV6.kicad_pcb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]
2026-09-24 Updated board project and gerber files
    [VFD_IV6-B_Cu.gbl, VFD_IV6-B_Mask.gbs, VFD_IV6-B_Paste.gbp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]
2026-09-29 Updated schematic and board
2026-10-12 Updated interactive BOM
2026-10-12 Updated Gerber files
